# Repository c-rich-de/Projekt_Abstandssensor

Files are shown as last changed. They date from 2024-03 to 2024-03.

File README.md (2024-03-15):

HTWK Leipzig | Embedded Systems
-------------------------------

Die Struktur ist folgendermaßen aufgebaut:
- 3d_data: Dateien, welche zum Bau der Sensorhalterung benötigt werden.
- datalogger: Excel-Tabellen, welche für die Auswertung genutzt wurden. Aufgezeichnet mit dem Datalogger des RPi Pico H.
- Beleg.pdf: Vollständige Beschreibung des Projektes von Anfang bis Ende.
- Dokumentation.pdf: Kurfassung mit den wichtigsten Eckdaten.
- main.py: Programm, welches auf dem RPi Pico H installiert ist.

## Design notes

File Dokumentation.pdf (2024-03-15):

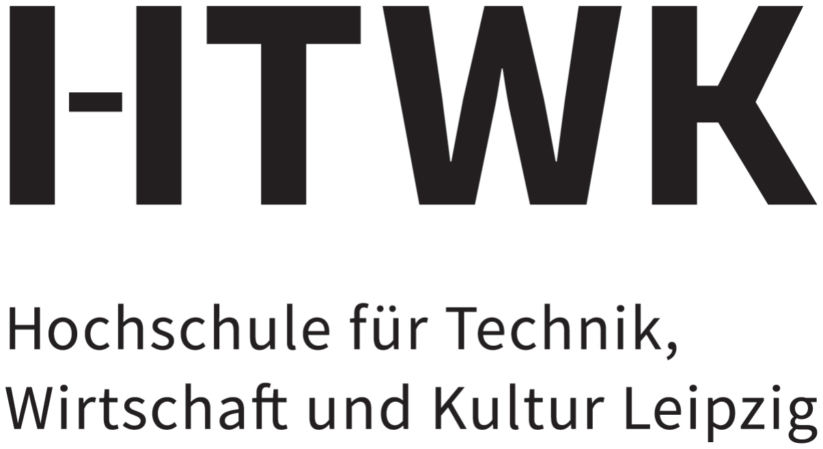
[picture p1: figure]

Fakultat Ingenieurwissenschaften ¨

5420 - Embedded Systems

# Dokumentation des Projekts Abstandssensor

Autor Thomas Diner Christian Richter

Betreuer Marco Braun
| Andreas Reinhold

GitHub

https://github.com/c-rich-de/Projekt Abstandssensor

15. März 2024

## Inhaltsverzeichnis

1 Vorwort | 1
2 Datenblatt des Sensors | 1
3 Pinout RPi Pico H | 5
4 Schaltplan | 5
5 Programm | 6
6 Anwendung | 8
7 Materialliste | 10

## 1 Vorwort

Die nachfolgende Dokumentation soll eine Hilfe dafur sein, den Sensor in Betrieb zu nehmen und ¨

einen Abstand zu messen.

## 2 Datenblatt des Sensors

1

# Microphotonic Devices (Micro-displacement Sensor)

# Z4D-C01

# Micro-displacement Sensor

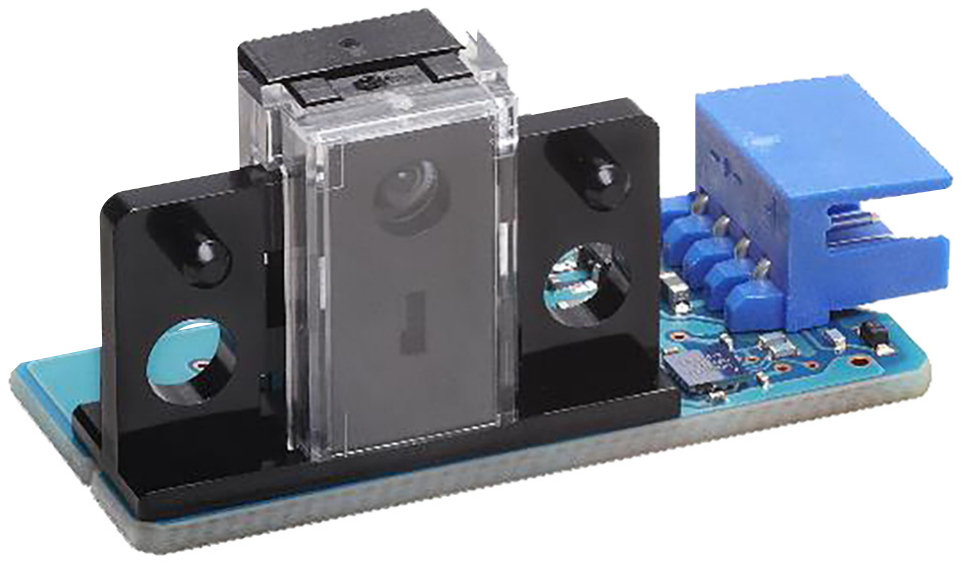
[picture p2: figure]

### - Enable to detect ±10 μm level displacement, applicable to detect

duplicated paper feeding or deflection amount.

### - Displacement output changes by object colors are stabilized with

signal divider circuit.
- Operating area = 6.5 ±1 mm.

# Ordering Information

## Micro-displacement Sensor

# Ratings, Characteristics and Exterior Specifications

## Absolute Maximum Ratings (Ta = 25°C)

## Characteristics (Ta = 25°C)

Object: N8.5 Munsell paper with a reflection factor of 70%.

*1. Distance from Mounting Reference Plane to Target.
*2. The sensitivity is defined as slope of the line and it represents the variation in the output voltage per unit length between different products.

*3. This is the value of the electrical noise width in the output signal converted to a distance under the following conditions.
(1) Noise width is measured in a waveform after the four times average with an oscilloscope.
(2) Ripple noise in the power supply voltage (Vcc): 10 mVp-p max.
(3) Distance from mounting reference plane to target: 6.5 mm
(4) Resolution is measured by the voltage of response delay time (tr2). *4. This is the peak-to-peak value of the deviation of the signal output from a straight line.
A linearity of 2% F.S. indicates the following value:
(1) Distance full-scale converted value: 2 mm × 0.02 = 0.04 mm (40 μm)
(2) Output voltage converted value: 1.4 mV/μm × 40 μm = 56 mV (for a sensor with a sensitivity of 1.4 mV/μm)

## Exterior Specification

## Electrical and Optical Characteristics (Ta = -10°C to 65°C)

*1. Load impedance (between OUT-GND) is set at more than 10 kΩ. *2. tr1: Rise time of output voltage from 10% to 90%.
*3. tr2: Setup time from PLS rising edge to measured output value rising edge.

Be sure to read Safety Precautions on page 3.

Item | Symbol | Rated value | Unit | Remarks
Supply voltage | VCC | 7 | V | ---
LED pulse light
emission control signal | PLS | 7 | V | LED
LED light emission pulse | tFP | 100 | ms | Please refer Pulsed Forward
| | | | Current Rated Curve
Operating temperature | Topr | -10 to +65 | °C | No freezing or condensation
Storage temperature | Tstg | -25 to +80 | °C | ---
Item | Value
Operating area *1 | 6.5 ±1 mm
Sensitivity variation *2 | -1.4 mV/μm ±10% max.
Resolution *3 | ±10 μm max.
Linearity *4 | 2% F.S. (full scale) max.

Sensitivity
variation =

V1 - V0
(mV/μm)

V0: Output voltage at the point d0 V1: Output voltage at the point d1 d0,d1: Distance between datum clamp face and detective object

2000

d0 | 5.5 mm
d1 | 7.5 mm

Connecting
method | Weight (g) | | Material
| | Case | Cover | Lens
Connector | 3.6 | Polycarbonate | Polycarbonate | PMMA
Item | Symbol | Rated value | Remarks
Power supply voltage | VCC | 5 V ±10% | Ripple (p-p): 10 mV p-p max.
Output voltage | OUT | 0.2 V to (VCC - 0.3) V | *1
Response delay time | tr1 | 100 μs max. | *2
| tr2 | 500 μs max. | *3
LED pulse light
emission control signal voltage | PLS | 3.5 V to VCC | ---

Downloaded from Arrow.com.

## Z4D-C01

## Engineering Data (Reference value)

## Circuit diagram/Connection diagram

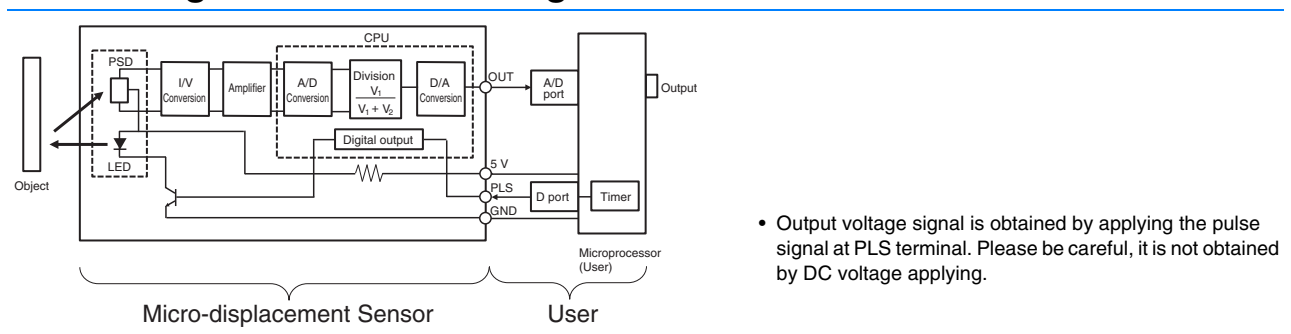
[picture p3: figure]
Object; PSD; Conversion; Amplifier; Division V1; D/A Conversion; LED; Digital output; CPU; OUT; PLS; GND; A/D port; D port; Timer; Microprocessor (User); Output; Micro-displacement Sensor; User; by DC voltage applying.

## Pulse Input and Sensor Output

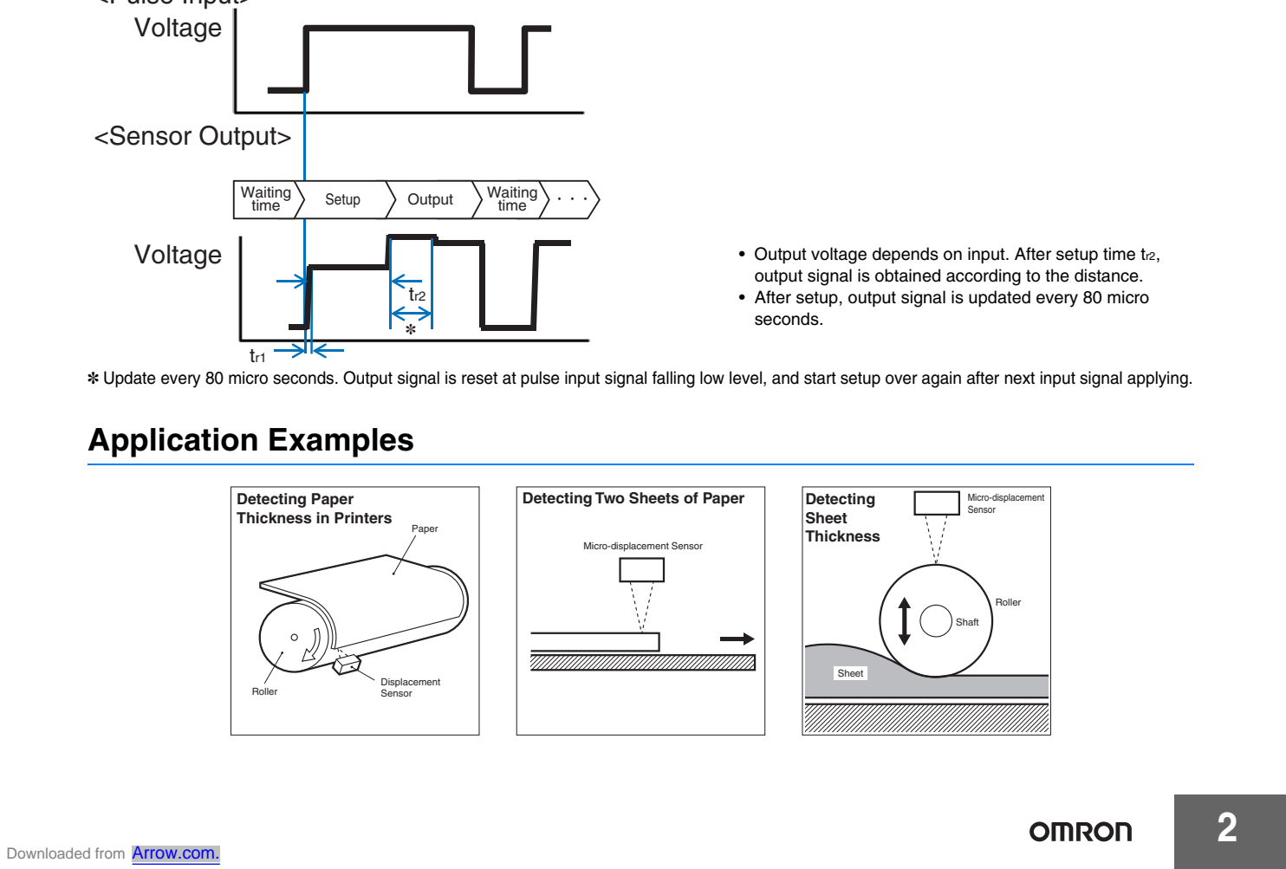
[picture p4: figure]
Application Examples; Voltage; <Sensor Output>; Waiting; time; Setup; Output; Waiting time; seconds.; Displacement; Roller; Sensor; Paper; Detecting Paper Thickness in Printers; Detecting Sheet Thickness; Detecting Two Sheets of Paper; Micro-displacement Sensor; Sheet; Shaft; Downloaded from Arrow.com.

* Update every 80 micro seconds. Output signal is reset at pulse input signal falling low level, and start setup over again after next input signal applying.

Fig 1. Operating Distance
Characteristics (Typical)

Fig 2. Dependency of Object on Reflection Factor (Typical)

Fig 3. Temperature
Characteristics (Typical)

Fig 4. Pulsed Forward
Current Rated Curve

5

4

3

2

1

0
5 | 6 | 7 5.5 | 6.5 | 7.5 | 8

Operating distance (mm)

Output voltage (V)

100 -50

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
0 | 20 | 40 | 60 | 80

Sensitivity change ratio (%)

Reflection factor of object (%)

0

-100

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
0 | 20 | 40 | 60 | 80 | 100

Output change ratio (mV)

-40 -20

Vcc = 5 V
Distance: 6.5 mm

Ambient temperature (°C)

0

0.1

1

10

100

20 | 40 | 60 | 80

Recommended
operating area
Duty ratio (%)= | ×100 tFP

tFP

T

T

Duty ratio (%)

Pulse width (tFP)

(ms)

- Output voltage signal is obtained by applying the pulse signal at PLS terminal. Please be careful, it is not obtained

### <Pulse Input>

- Output voltage depends on input. After setup time tr2, output signal is obtained according to the distance.
- After setup, output signal is updated every 80 micro

3

## Z4D-C01

## Safety Precautions

To ensure safe operation, be sure to read and follow the Instruction Manual provided with the Sensor.

This product is not designed or rated for ensuring safety of persons either directly or indirectly. Do not use it for such purposes.

Do not use the product with a voltage or current that exceeds the rated range.

Applying a voltage or current that is higher than the rated range may result in explosion or fire.
Do not miswire such as the polarity of the power supply voltage.
Otherwise the product may be damaged or it may burn.
This product does not resist water. Do not use the product in places where water or oil may be sprayed onto the product.

Do not use the product in atmospheres or environments that exceed product ratings. This product is for surface mounting. Refer to Soldering Information, Storage and Baking for details.
Dispose of this product as industrial waste. Because the resolution of this sensor is very small, output error may occur due to noise from the power supply.
The ripple noise of the power supply should be 10mVp-P or less. Add averaging and filters as needed to reduce the effects of noise.
Dimensions | (Unit: mm)

### Micro-displacement Sensor

CAUTION

Precautions for Safe Use

Precautions for Correct Use

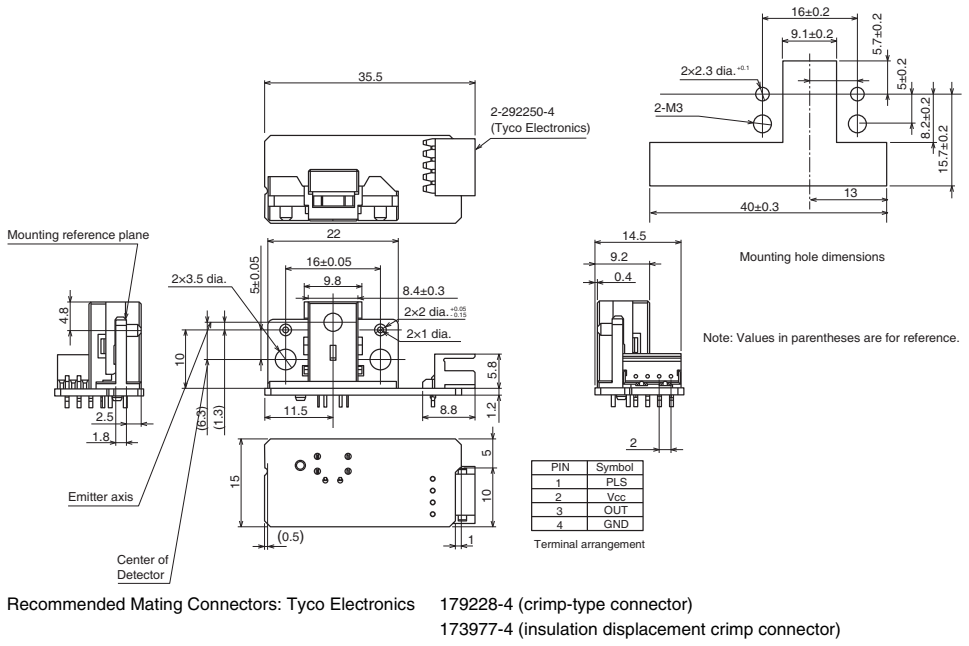
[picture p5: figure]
2×2.3 dia.; Mounting reference plane; Mounting hole dimensions; Emitter axis; Center of Detector; 2×3.5 dia.; 2×2 dia.; 2×1 dia.; 2-292250-4 (Tyco Electronics); PIN; PLS; OUT; Vcc; GND; Symbol; Terminal arrangement (0.5); Recommended Mating Connectors: Tyco Electronics; 179228-4 (crimp-type connector); 173977-4 (insulation displacement crimp connector)

Note: Values in parentheses are for reference.

Z4D-C01

Downloaded from Arrow.com.

Der Omron Z4D-C01 Abstandssensor besitzt 4 Anschlusse: ¨

- 1 = PLS (blau): hier wird der benötigte Puls angelegt, welcher die Infrarot LED arbeiten

lässt

- 2 = Vcc (schwarz): hier wird die Versorgungsspannung angelegt, die der Sensor benötigt
- 3 = OUT (weiß): hier werden die analogen Daten (eine Spannung) ausgegeben, die der Sensor

erfasst

- 4 = GND (lila) (Ground): hier wird die Masse angeschlossen, um einen geschlossenen Strom-

kreis herzustellen

Als Mikrocontroller haben wir den Raspberry Pi Pico H (2021) eingesetzt und fur die Program- ¨

mierung die Thonny IDE benutzt. Als Programmiersprache nutzen wir Python.

## 3 Pinout RPi Pico H

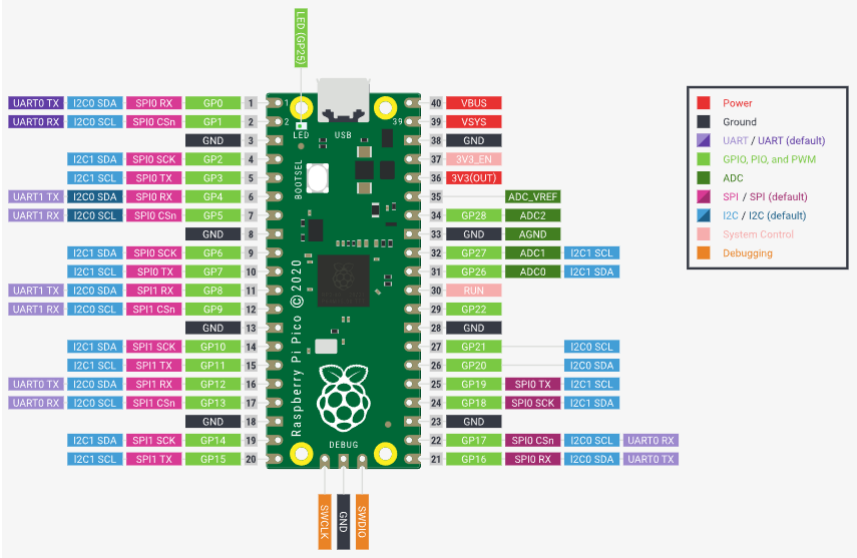
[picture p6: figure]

## 4 Schaltplan

Es ist darauf zu achten, dass der ADC Pin des Raspberry Pi Pico nur maximal 3,3 V aufnehmen

kann. Somit ist ein geeigneter Spannungsteiler vor dem ADC pin und nach dem ’Out’ des Sensors zu schalten. In diesem Fall wurde 40kΩ und 70kΩ benutzt um das Ausgangssignal des Sensors

einzuschränken (siehe Schaltplan).

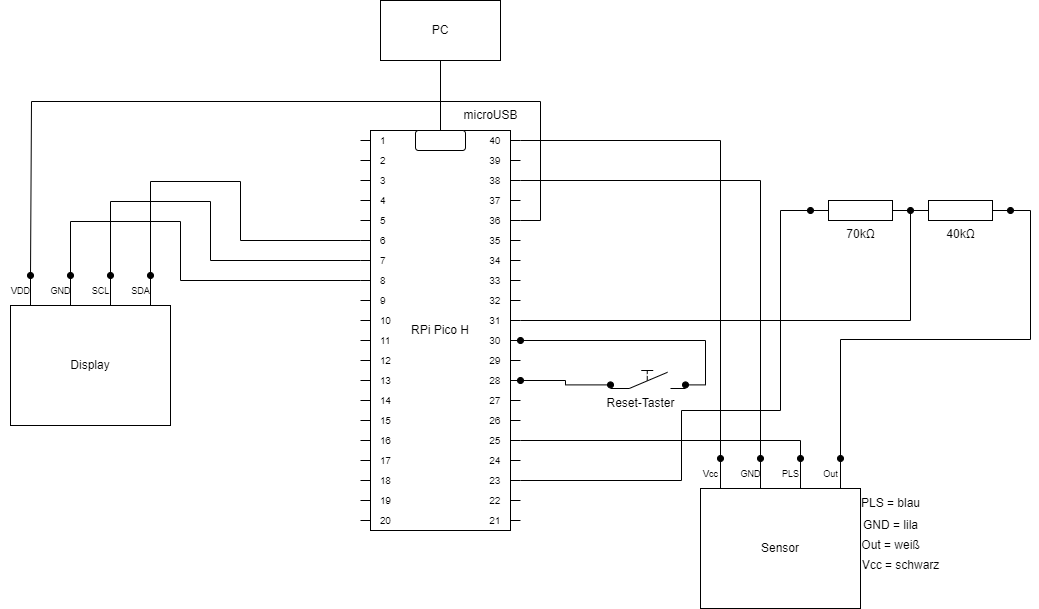
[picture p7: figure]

## 5 Programm

Um den RPi Pico H auch nutzen zu können, muss dieser vorher ausgewählt werden:

Run → Configure Interpreter → Auswählen von Micropython und dem angeschlossenen Port.

Der Output ist im Verzeichnis des RPi zu finden, unter dem Namen ’data.csv’. Dieses wird bei

jedem Programmneustart uberschrieben. ¨

from machine import ADC | #Initialisieren des ADC
from time import sleep | #Initialisieren Sleep-Befehls aus dem 'time' Moduls

#I2C betriebenenes SH1106 OLED-Display

from machine import I2C, ADC

from sh1106 import SH1106_I2C

import framebuf

WIDTH | = 128 | #Breite des OLED-Displays
HEIGHT = 64 | #Höhe des OLED-Displays

i2c = I2C(0) | #I2C mit I2C0 defaults, SCL=Pin(GP5), SDA=Pin(GP4), freq=400000
print("I2C Address | : "+hex(i2c.scan()[0]).upper()) #Display device address
print("I2C Configuration: "+str(i2c)) | #Display I2C config
oled = SH1106_I2C(WIDTH, HEIGHT, i2c) | #Initialisierung des OLED-Displays
oled.rotate(True) | #Drehen des Bildes um 180 Grad

#Sensor-Anschluss

from machine import Pin, PWM | #Initialisierung der PWM-Funktionseinheit
pwm = PWM(Pin(19)) | #und des GPIO-Pins
pwm.freq(13) | #Einstellen der Frequenz für die PWM
pwm.duty_u16(65535) | #Einstellen vom Tastgrad (Duty Cycle)
pot = ADC(Pin(26)) | #Festlegung des Pins für den ADC

#log-file erstellen

file = open("data.csv","w")

#Definition von max und min

max_abstand = 0 | #umgekehrte Proportionalität

min_abstand = 65535

#Durchlauf mit Anzeige von Werten

while True:

#ADC

pot_value = pot.read_u16()

#Berechnung der Anzeigewerte

pot_spannung = (3.3 * pot_value)/65535

abstand = (pot_spannung - 5.61)/(-1.05)

max_abstand = max(abstand, max_abstand)

min_abstand = min(abstand, min_abstand)

diff = max_abstand - min_abstand

#Ausgabe in der Shell zur Kontrolle

print(pot_value)

print(pot_spannung)

print(abstand)

#OLED-Display (l/r, o/u)

#Abstandsanzeige

oled.text("Abstand:",5,5)

oled.text(str(abstand)[:5],5,15)

oled.text("mm",55,15)

#Füller

oled.text("-------------------",0,23)

#Max/Min Anzeige

oled.text("max: min:",5,30)

oled.text(str(max_abstand)[:5],5,40)

oled.text(str(min_abstand)[:5],60,40)

oled.text("mm",110,40)

#Differenzanzeige

oled.text("Diff.:",5,55)

oled.text(str(diff)[:5],60,55)

oled.text("mm",110,55)

#Ausgabe des Displays

oled.show()

sleep(0.08) | #für weniger häufige Aktualisierung der Messwerte (auf pwm.freq abgestimmt!)
oled.fill(0) | #reset des OLED-Displays auf schwarz

#Füllen des log-files

file.write("Wert: " + str(pot_value) + "| Spannung (V): " + str(pot_spannung) +

"| Abstand (mm): " + str(abstand) + "\n")

file.flush()

## 6 Anwendung

Wenn man nun das obige Programm und die Betriebsmittel nach dem Schaltplan anschließt und

aufbaut, ist man in der Lage mit jenem Abstandssensor einen Abstand zu messen, welcher jedoch

stark von den Angaben des Datenblatts abweicht.

- Der im Datenblatt gegebene Arbeitsbereich von ±6, 5mm wurde bereits anhand der ersten

Experimente widerlegt. Wir haben mit Hilfe der ausgegebenen Digitalwerte nur einen Ar-

beitsbereich von etwa 2,65 mm nachweisen können.

- Wir haben festgestellt, dass man auch nur maximal (2, 55 ± 0, 15) mm an das zu messende

Objekt herankommt und nicht weiter als (5, 2 ± 0, 15) mm weg darf, da der Sensor dann

unverwertbare Werte ausgibt.

- Es wurde auch nicht der volle Umfang der 16 bit, also 65535 Werte ausgereizt, sondern nur etwa 53208 Werte (56683 - 3475).
- Wichtig ist hier aber auch die Verwendung von weißem (Drucker-)Papier, da sich schnell

gezeigt hat, dass stark glänzende Flächen mit einer hohen Fehlerabweichung einhergehen.

- ebenfalls empfielt es sich als Messpunkt eine möglichst ebene Fläche zu wählen
- Fur eine genaue Analyse empfiehlt es sich ein Oszilloskop heranzuziehen. Der Sensor samt ¨

Display ist eher eine Momentanwertanzeige bzw. zum Aufzeichnen von Daten geeignet.

## 7 Materialliste

- Mikrocontroller Raspberry Pi Pico
- 1,3 Zoll OLED I2C 128 x 64 Pixel Display
- 75 kΩ und 40 kΩ Widerstände
- Anschlussbuchsen fur Jumperwires ¨
- Reset-Knopf
- OMRON Z4D-C01 Abstandssensor
- Pico Breadboard
- USB-A zu micro-USB Leitung
- Jumperwires
- Teststation bestehend aus:

– Gestell aus Aluminium

– Frequenzumrichter (Combivert G6 der Firma KEB Automation KG)

– Motor (Firma: KEB, 3-phasig, 0,37 kW, Dreieck 230 V/ 1,73 A, Stern 400 V/ 1,00 A,

cos ϕ = 0,71; u = 1410 1/min)

– Bedienfeld fur die leichte Bedienung des Frequenzumrichters ¨

– dazugehörige Verkabelung

– herkömmliches Druckerpapier

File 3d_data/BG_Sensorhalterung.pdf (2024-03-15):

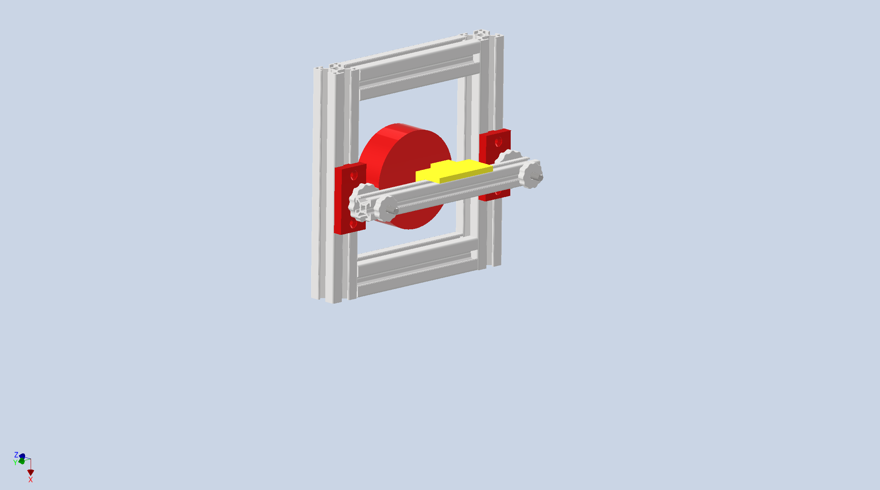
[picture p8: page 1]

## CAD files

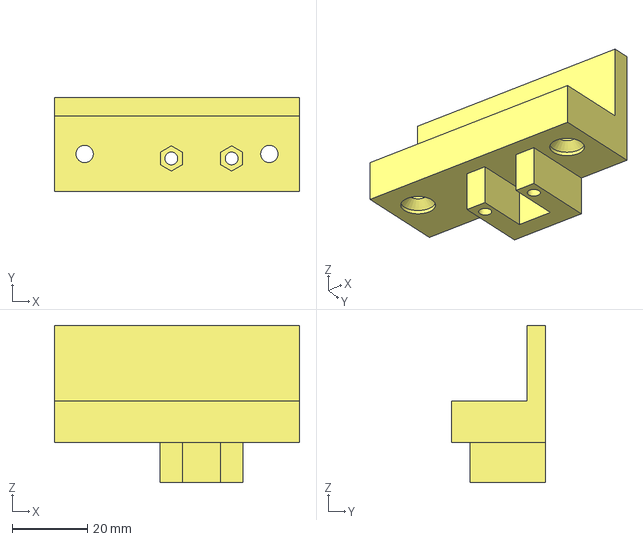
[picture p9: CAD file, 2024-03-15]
3d_data/Sensorhalterung.stp
65.0 x 25.0 x 41.7 mm

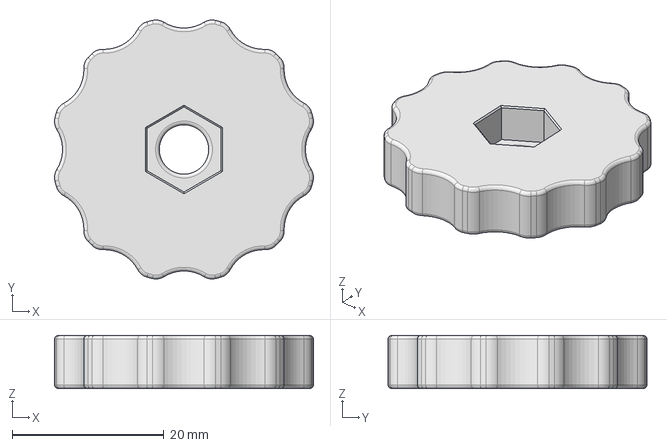
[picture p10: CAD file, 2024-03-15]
3d_data/Mutter_M6.stp
34.1 x 34.1 x 7.00 mm

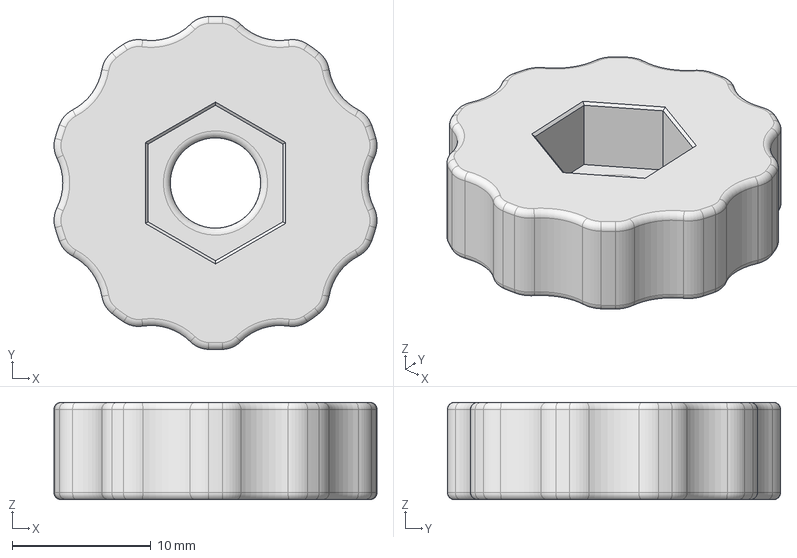
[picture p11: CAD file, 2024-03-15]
3d_data/Mutter_M6_oben.stp
23.3 x 24.0 x 7.00 mm

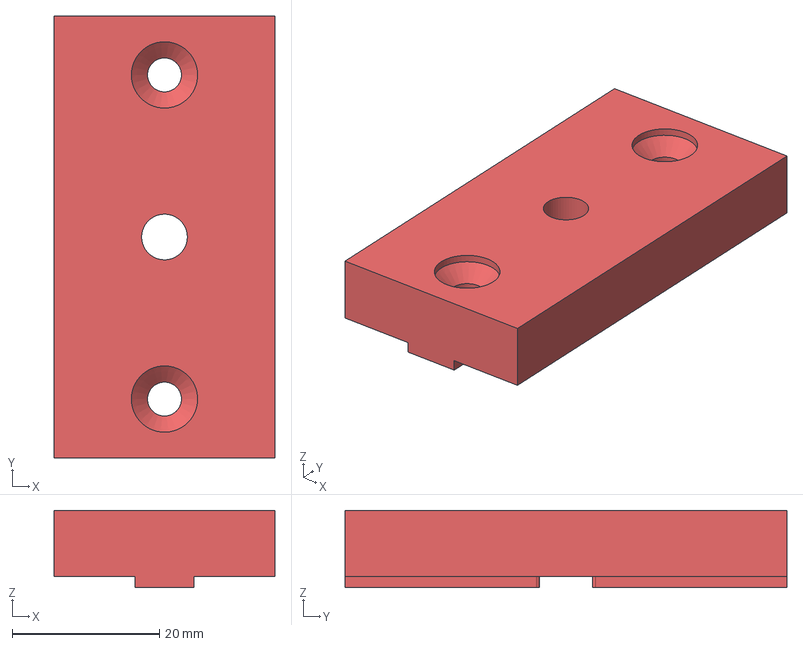
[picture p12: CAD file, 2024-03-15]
3d_data/Halterung_vertikal.stp
30.0 x 60.0 x 10.5 mm

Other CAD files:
3d_data/Halterung_vertikal.stl
3d_data/Mutter_M6.stl
3d_data/Mutter_M6_oben.stl
3d_data/Sensorhalterung.stl

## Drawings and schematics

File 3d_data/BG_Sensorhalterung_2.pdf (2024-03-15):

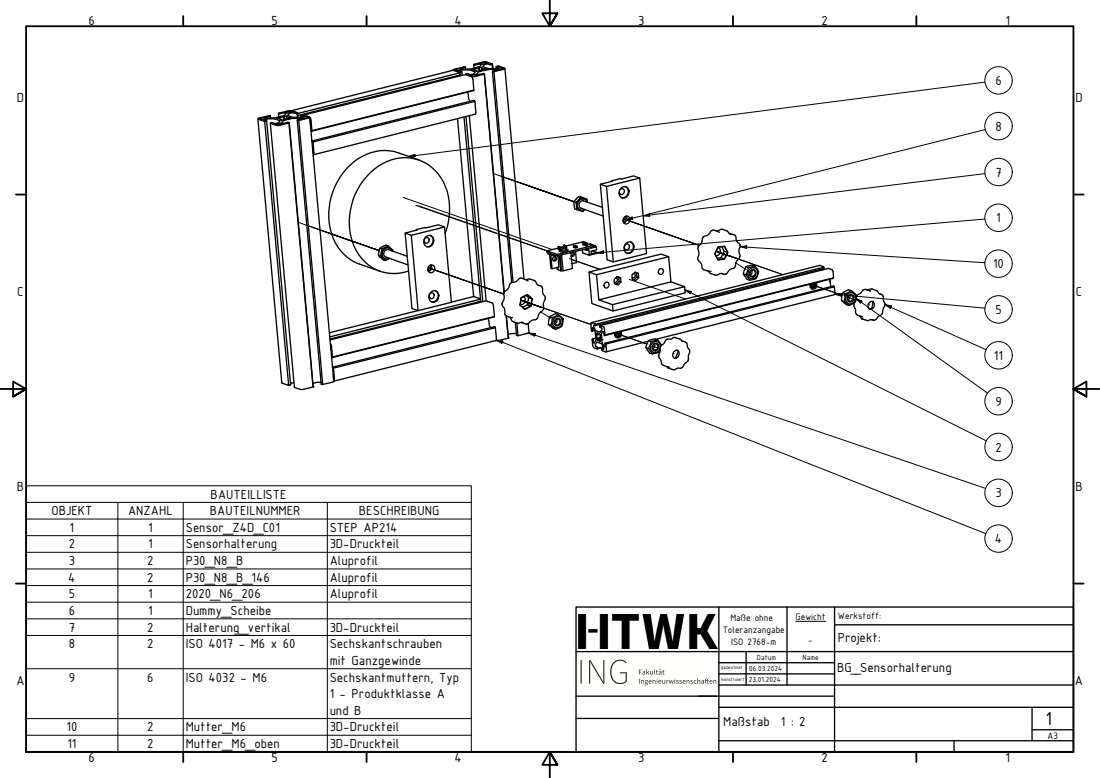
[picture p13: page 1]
Maße ohne; ISO 2768-m; Maßstab 1 : 2

OBJEKT | ANZAHL | BAUTEILNUMMER | BESCHREIBUNG
1 | 1 | Sensor_Z4D_C01 | STEP AP214
2 | 1 | Sensorhalterung | 3D-Druckteil
3 | 2 | P30_N8_B | Aluprofil
4 | 2 | P30_N8_B_146 | Aluprofil
5 | 1 | 2020_N6_206 | Aluprofil
6 | 1 | Dummy_Scheibe
7 | 2 | Halterung_vertikal | 3D-Druckteil
8 | 2 | ISO 4017 - M6 x 60 | Sechskantschrauben mit Ganzgewinde

Datum | Name | BG_Sensorhalterung

gezeichnet | 06.03.2024

9 | 6 | ISO 4032 - M6 | Sechskantmuttern, Typ 1 - Produktklasse A und B

konstruiert | 23.01.2024

10 | 2 | Mutter_M6 | 3D-Druckteil
11 | 2 | Mutter_M6_oben | 3D-Druckteil
